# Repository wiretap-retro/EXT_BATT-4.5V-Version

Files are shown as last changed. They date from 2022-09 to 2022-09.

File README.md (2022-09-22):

# EXT_BATT 4.5V Version
A battery supply for retro motherboards with an EXT_BATT header.

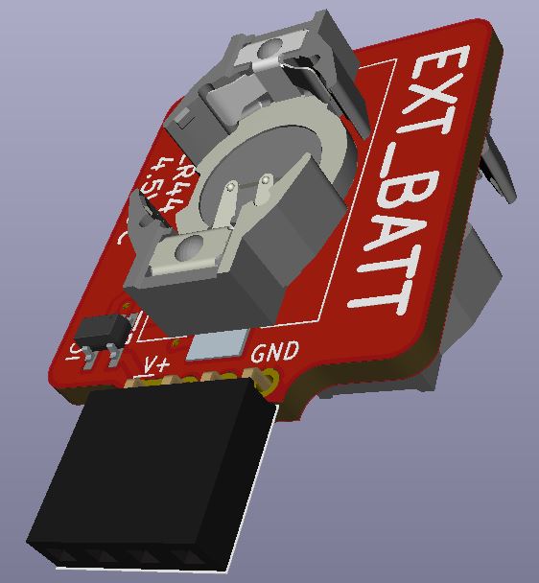
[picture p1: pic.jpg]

\
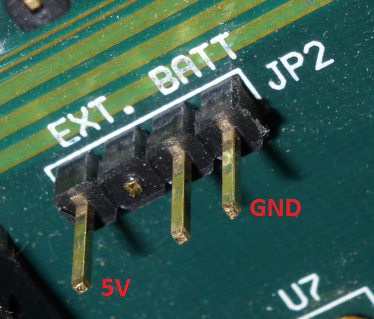
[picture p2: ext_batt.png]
mobo

\
^--photo from minuszerodegrees showing EXT_BATT header

## Info
I have quite a few 386 and 486 motherboards that have an EXT_BATT header, but I've removed the rechargable Varta. This PCB project is aimed at using the EXT_BATT header to provide a solution to keep your CMOS settings saved and RTC ticking. The MAX40200 chip provides for "ideal diode" functionality with less than a 43mV drop in voltage. It also prevents a charge circuit from trying to charge the LR44 / 357 type battery if the motherboard happens to have a charge circuit on the EXT_BATT header. (rare occurences). I prefer this board because the batteries are cheap, last a long time, and the EXT_BATT header is usually in an easier spot to get to than where the Varta battery is crammed on most boards. I recommend using Japanese made 357 silver-oxide type batteries in this, as they tend not to corrode, and they last much longer. Check the batteries every few years.

## BOM
* This circuit board, ordered from your fabricator of choice. (JLCPCB, PCBway, OSH Park, etc.)
* Maxim MAX40200AUK+T Ideal Diode
* 3x Renata SMTU357-LF battery holder
* 1x04 2.54mm pitch right angle pin socket, or 1x04 2.54mm pitch straight pin socket, or 1x04 2.54mm male pin headers (see below for mounting orientations)
* 3x LR44 / 357 batteries

## Installation
Plug the completed board into the EXT_BATT header. Several motherboards also use an INTERNAL/EXTERNAL jumper to select between the factory installed battery and the EXT_BATT header.
\
\
Mounting orientations:
* Vertical - this PCB sits about 36mm tall when installed vertically. 
* Horizontal - may be possible depending on your board's EXT_BATT header location/orientation and other nearby components.
* Remote - use pin header extension wires to connect to the EXT_BATT header and put the PCB somewhere else in the case.

## Other
Reference material for retro motherboard batteries: http://minuszerodegrees.net/battery/cmos/vintage_motherboard_batteries.htm
\
This project is open source, feel free to do what you want with it.

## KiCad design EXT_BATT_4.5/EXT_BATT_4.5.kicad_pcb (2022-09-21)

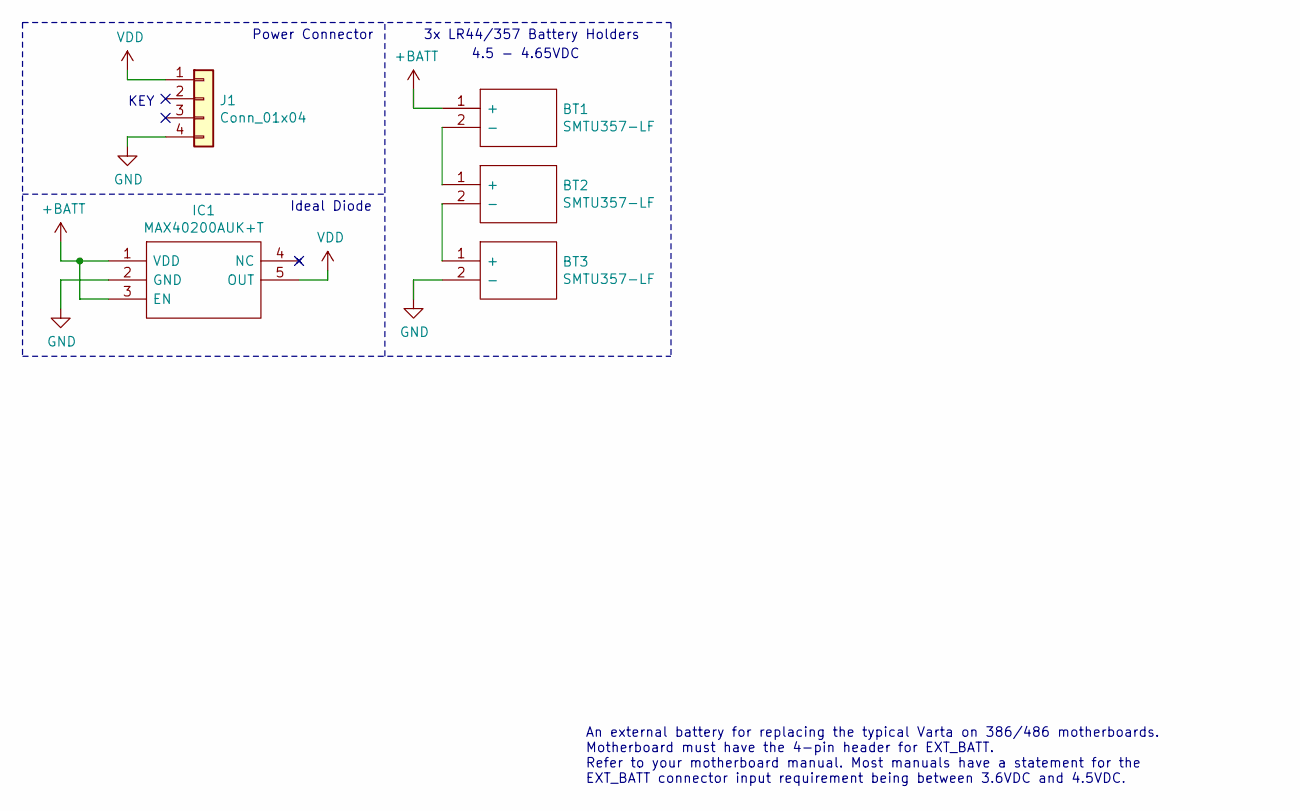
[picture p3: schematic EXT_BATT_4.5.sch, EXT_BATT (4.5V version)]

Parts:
BT1, BT2, BT3: SMTU357-LF; SMTU357LF; Mouser Part Number 614-SMTU357-LF
IC1: MAX40200AUK+T; SOT95P280X145-5N; Mouser Part Number 700-MAX40200AUK+T
J1: Conn_01x04; PinSocket_1x04_P2.54mm_Horizontal

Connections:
+BATT: BT1.1 (+), IC1.1 (VDD), IC1.3 (EN)
GND: BT3.2 (-), IC1.2 (GND), J1.4
unnamed: BT1.2 (-), BT2.1 (+)
unnamed: BT2.2 (-), BT3.1 (+)
VDD: IC1.5 (OUT), J1.1

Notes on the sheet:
KEY
3x LR44/357 Battery Holders
4.5 - 4.65VDC
Power Connector
Ideal Diode
An external battery for replacing the typical Varta on 386/486 motherboards. Motherboard must have the 4-pin header for EXT_BATT. Refer to your motherboard manual. Most manuals have a statement for the EXT_BATT connector input requirement being between 3.6VDC and 4.5VDC.

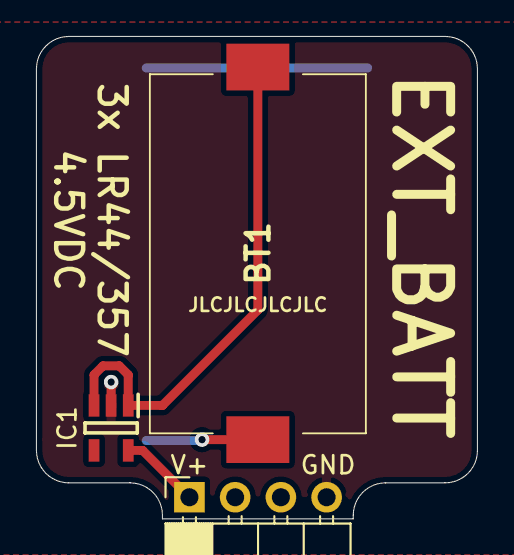
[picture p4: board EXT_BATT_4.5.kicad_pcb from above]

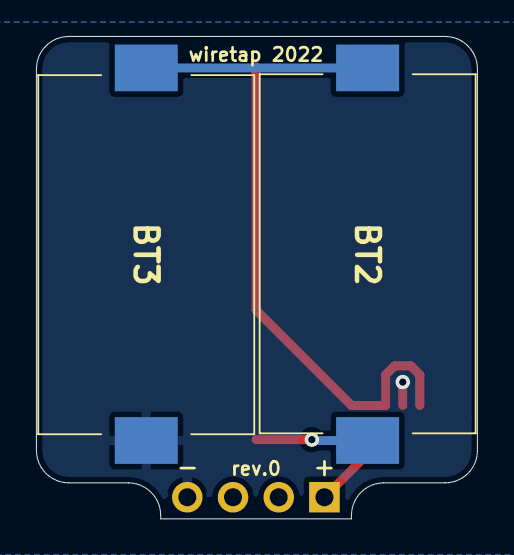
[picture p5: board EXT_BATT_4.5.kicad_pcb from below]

Board: 2 copper layers, 24.5 x 26.8 mm, 5 parts (2 on the bottom side), 5 nets.
